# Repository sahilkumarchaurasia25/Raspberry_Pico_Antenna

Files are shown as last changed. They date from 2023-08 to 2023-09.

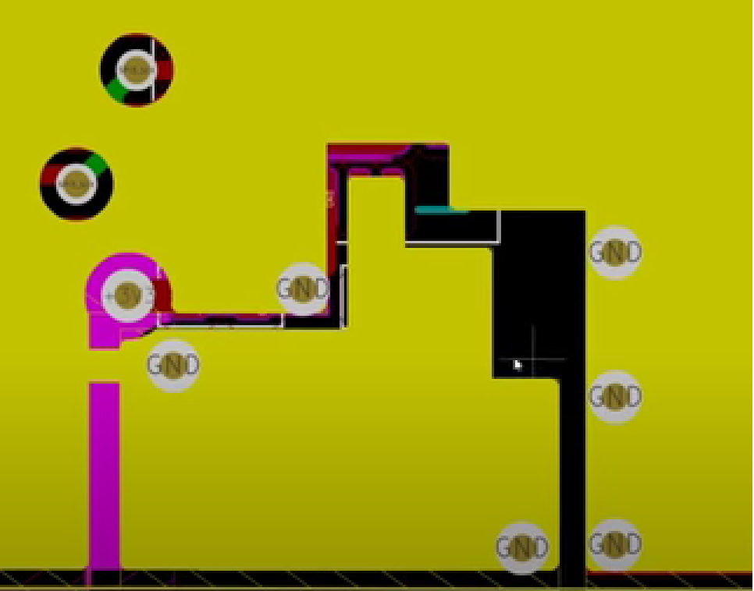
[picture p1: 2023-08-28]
DATASHEET/crystal.png

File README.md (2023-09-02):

# Raspberry_Pico_Antenna

You can refer the code from github repository by AndyRids, https://github.com/AndyRids/pico-nrf24 
Front view

Back View

Pcb design


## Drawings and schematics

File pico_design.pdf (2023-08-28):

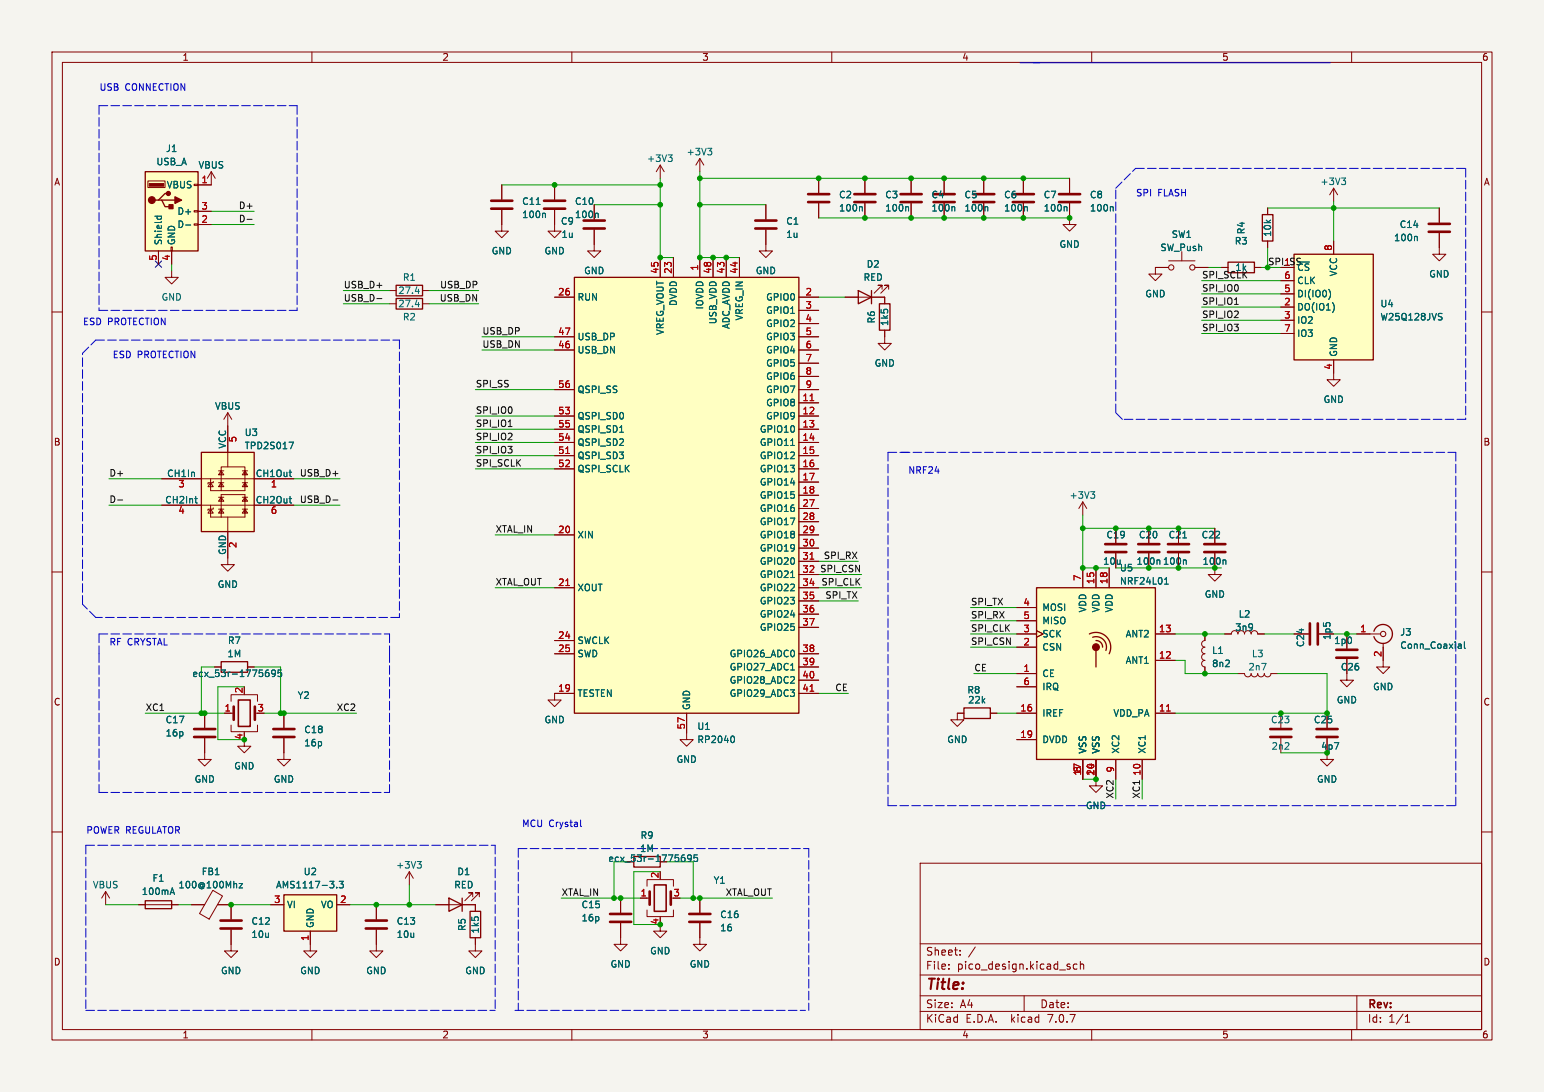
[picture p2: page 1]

1 GPIO8 11 GPIO9 12 GPIO10 13 GPIO11 14 GPIO12 15 GPIO13 16 GPIO14 17 GPIO15 18 TESTEN 19 GPIO0 2 XIN 20 XOUT 21 DVDD 23 SWCLK 24 SWD 25 RUN 26 GPIO16 27 GPIO17 28 GPIO18 29 GPIO1 3 GPIO19 30 GPIO20 31 GPIO21 32 GPIO22 34 GPIO23 35 GPIO24 36 GPIO25 37 GPIO26_ADC0 38 GPIO27_ADC1 39 GPIO2 4 GPIO28_ADC2 40 GPIO29_ADC3 41 ADC_AVDD 43 VREG_IN 44 VREG_VOUT 45 USB_DN 46 USB_DP 47 USB_VDD 48 GPIO3 5 QSPI_SD3 51 QSPI_SCLK 52 QSPI_SD0 53 QSPI_SD2 54 QSPI_SD1 55 QSPI_SS 56 GND 57 GPIO4 6 GPIO5 7 GPIO6 8 GPIO7 9 U1 RP2040 GND

1 GPIO8 11 GPIO9 12 GPIO10 13 GPIO11 14 GPIO12 15 GPIO13 16 GPIO14 17 GPIO15 18 TESTEN 19 GPIO0 2 XIN 20 XOUT 21 DVDD 23 SWCLK 24 SWD 25 RUN 26 GPIO16 27 GPIO17 28 GPIO18 29 GPIO1 3 GPIO19 30 GPIO20 31 GPIO21 32 GPIO22 34 GPIO23 35 GPIO24 36 GPIO25 37 GPIO26_ADC0 38 GPIO27_ADC1 39 GPIO2 4 GPIO28_ADC2 40 GPIO29_ADC3 41 ADC_AVDD 43 VREG_IN 44 VREG_VOUT 45 USB_DN 46 USB_DP 47 USB_VDD 48 GPIO3 5 QSPI_SD3 51 QSPI_SCLK 52 QSPI_SD0 53 QSPI_SD2 54 QSPI_SD1 55 QSPI_SS 56 GND 57 GPIO4 6 GPIO5 7 GPIO6 8 GPIO7 9 GND

Id: 1/1 Title: File: pico_design.kicad_sch Sheet: / IOVDD

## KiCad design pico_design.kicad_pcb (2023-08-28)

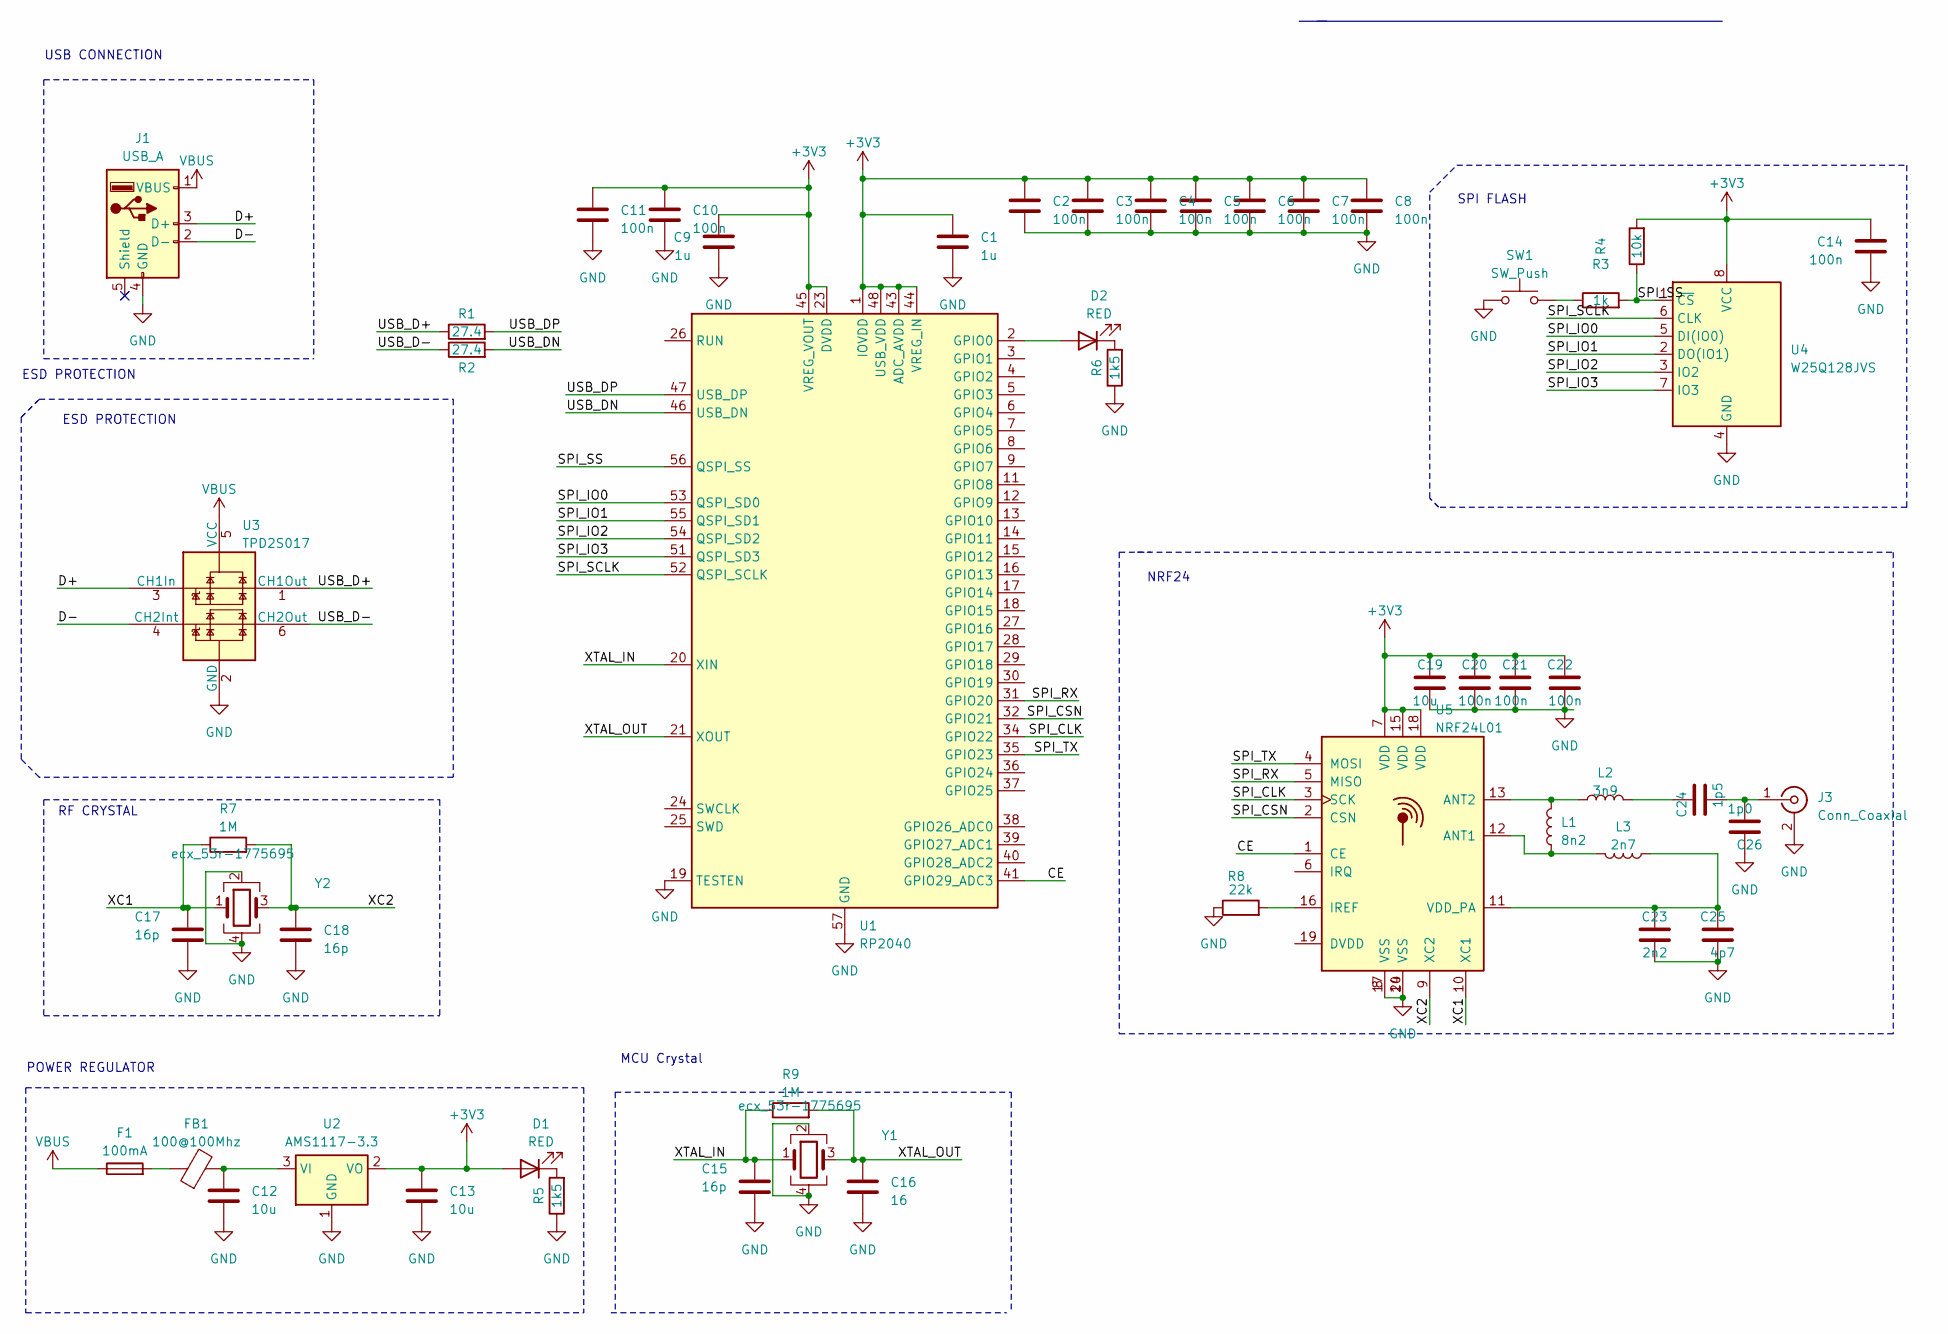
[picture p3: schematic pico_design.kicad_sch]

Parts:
C1, C9: 1u; C_0805_2012Metric
C2, C3, C4, C5, C6, C7, C8, C10, C11, C14, C20, C21, C22: 100n; C_0402_1005Metric
C12, C13, C19: 10u; C_0805_2012Metric
C15, C17, C18: 16p; C_0402_1005Metric
C16: 16; C_0402_1005Metric
C23: 2n2; C_0402_1005Metric
C24: 1p5; C_0402_1005Metric
C25: 4p7; C_0402_1005Metric
C26: 1p0; C_0402_1005Metric
D1, D2: RED; LED_0402_1005Metric
F1: 100mA; Fuse_0805_2012Metric
FB1: 100@100Mhz; C_0805_2012Metric
J1: USB_A; USB_A_CNCTech_1001-011-01101_Horizontal
J3: Conn_Coaxial; SMA_Samtec_SMA-J-P-X-ST-EM1_EdgeMount
L1: 8n2; L_0402_1005Metric
L2: 3n9; L_0402_1005Metric
L3: 2n7; L_0402_1005Metric
R1, R2: 27.4; R_0402_1005Metric
R3: 1k; R_0402_1005Metric
R4: 10k; R_0402_1005Metric
R5, R6: 1k5; R_0402_1005Metric
R7, R9: 1M; R_0402_1005Metric
R8: 22k; R_0402_1005Metric
SW1: SW_Push; SW_SPST_B3U-1000P
U1: RP2040; QFN-56-1EP_7x7mm_P0.4mm_EP3.2x3.2mm
U2: AMS1117-3.3; SOT-223-3_TabPin2
U3: TPD2S017; SOT-23-6
U4: W25Q128JVS; SOIC-8_5.23x5.23mm_P1.27mm
U5: NRF24L01; QFN-20-1EP_4x4mm_P0.5mm_EP2.5x2.5mm
Y1, Y2: ecx_53r-1775695; Crystal_SMD_SeikoEpson_TSX3225-4Pin_3.2x2.5mm

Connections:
+3V3: C1.1, C2.1, C3.1, C4.1, C5.1, C6.1, C7.1, C8.1, C9.1, C10.1, C11.1, C13.1, C14.1, C19.1, C20.1, C21.1, C22.1, D1.2 (A), R4.2, U1.1 (IOVDD), U1.10 (IOVDD), U1.22 (IOVDD), U1.23 (DVDD), U1.33 (IOVDD), U1.42 (IOVDD), U1.43 (ADC_AVDD), U1.44 (VREG_IN), U1.45 (VREG_VOUT), U1.48 (USB_VDD), U1.49 (IOVDD), U1.50 (DVDD), U2.2 (VO), U4.8 (VCC), U5.7 (VDD), U5.15 (VDD), U5.18 (VDD)
/CE: U1.41 (GPIO29_ADC3), U5.1 (CE)
/D+: J1.3 (D+), U3.3 (CH1In)
/D-: J1.2 (D-), U3.4 (CH2Int)
/SPI_CLK: U1.34 (GPIO22), U5.3 (SCK)
/SPI_CSN: U1.32 (GPIO21), U5.2 (CSN)
/SPI_IO0: U1.53 (QSPI_SD0), U4.5 (DI(IO0))
/SPI_IO1: U1.55 (QSPI_SD1), U4.2 (DO(IO1))
/SPI_IO2: U1.54 (QSPI_SD2), U4.3 (IO2)
/SPI_IO3: U1.51 (QSPI_SD3), U4.7 (IO3)
/SPI_RX: U1.31 (GPIO20), U5.5 (MISO)
/SPI_SCLK: U1.52 (QSPI_SCLK), U4.6 (CLK)
/SPI_SS: R3.2, R4.1, U1.56 (QSPI_SS), U4.1 (~CS)
/SPI_TX: U1.35 (GPIO23), U5.4 (MOSI)
/USB_D+: R1.1, U3.1 (CH1Out)
/USB_D-: R2.1, U3.6 (CH2Out)
/USB_DN: R2.2, U1.46 (USB_DN)
/USB_DP: R1.2, U1.47 (USB_DP)
/XC1: C17.1, R7.1, U5.10 (XC1), Y2.1
/XC2: C18.1, R7.2, U5.9 (XC2), Y2.3
/XTAL_IN: C15.1, R9.1, U1.20 (XIN), Y1.1
/XTAL_OUT: C16.1, R9.2, U1.21 (XOUT), Y1.3
GND: C1.2, C2.2, C3.2, C4.2, C5.2, C6.2, C7.2, C8.2, C9.2, C10.2, C11.2, C12.2, C13.2, C14.2, C15.2, C16.2, C17.2, C18.2, C19.2, C20.2, C21.2, C22.2, C23.2, C25.2, C26.1, J1.4 (GND), J3.2 (Ext), R5.1, R6.1, R8.1, SW1.1, U1.19 (TESTEN), U1.57 (GND), U2.1 (GND), U3.2 (GND), U4.4 (GND), U5.8 (VSS), U5.14 (VSS), U5.17 (VSS), U5.20 (VSS), Y1.2, Y1.4, Y2.2, Y2.4
unnamed: C24.1, L2.2
unnamed: D1.1 (K), R5.2
unnamed: D2.2 (A), U1.2 (GPIO0)
unnamed: D2.1 (K), R6.2
unnamed: F1.2, FB1.1
unnamed: C24.2, C26.2, J3.1 (In)
unnamed: R3.1, SW1.2
unnamed: C12.1, FB1.2, U2.3 (VI)
unnamed: L1.1, L3.2, U5.12 (ANT1)
unnamed: L1.2, L2.1, U5.13 (ANT2)
unnamed: R8.2, U5.16 (IREF)
unnamed: C23.1, C25.1, L3.1, U5.11 (VDD_PA)
VBUS: F1.1, J1.1 (VBUS), U3.5 (VCC)

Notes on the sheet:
POWER REGULATOR
NRF24
RF CRYSTAL
MCU Crystal
USB CONNECTION
ESD PROTECTION
ESD PROTECTION
SPI FLASH

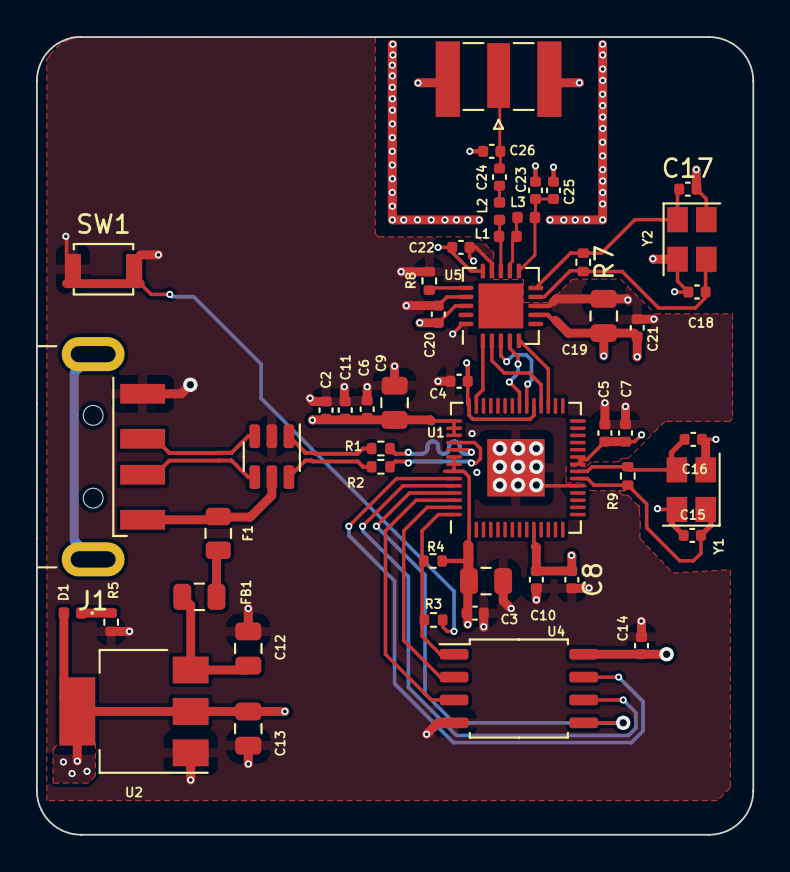
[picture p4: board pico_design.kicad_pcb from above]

Board: 4 copper layers, 39.8 x 44.3 mm, 49 parts (0 on the bottom side), 34 nets.
